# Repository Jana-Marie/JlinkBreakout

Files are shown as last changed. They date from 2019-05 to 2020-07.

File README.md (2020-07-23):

# JlinkBreakout

Segger Jlink to Tag-Connect/SWD breakout board.

## [V2](V2/)
Notes:
 - Use a right-angle 2 row, 20 position 0.1" (2.54mm) female header/socket
     + https://lcsc.com/product-detail/Pin-Header-Female-Header_Ckmtw-Shenzhen-Cankemeng-C124406_C124406.html
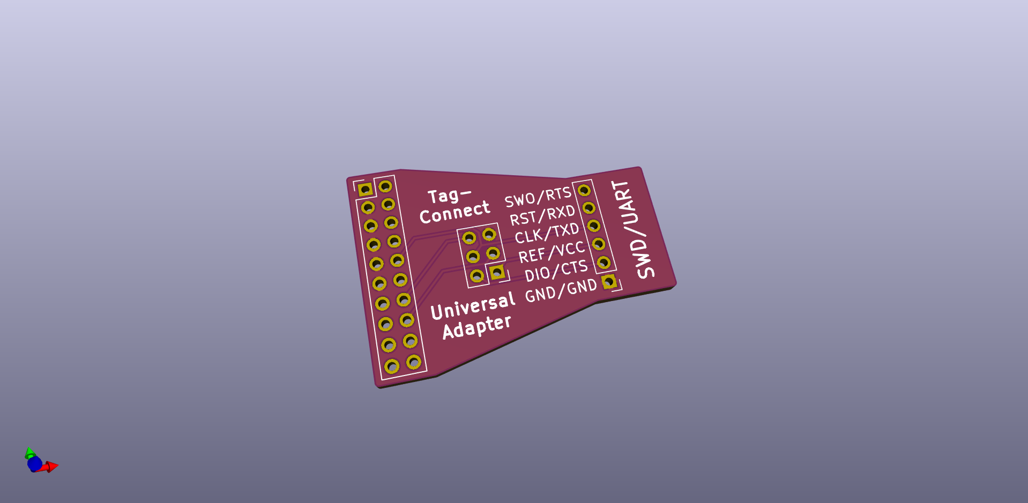
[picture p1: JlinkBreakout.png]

## [V3](V3/)
- Adds a voltage regulator with selectable output voltage (3.3V, 2.5V, 1.8V, External power)
- JST-XH connector for SWD
- 2x3 IDC Tag-connect header
- JTAG connector is standard 2 row, 20 position 0.1" (2.54mm) female header/socker, mounted on pcb edge
    + https://lcsc.com/product-detail/Pin-Header-Female-Header_BOOMELE-Boom-Precision-Elec-C30867_C30867.html
        * Pin thickness: 0.32mm to .064mm
        * Pin-pin clearance: 2.22mm to 1.9mm
    + Standard 1.6mm (0.062") PCB should be solderable, but there will be a gap, or 2mm (0.079") PCB would leave less clearance
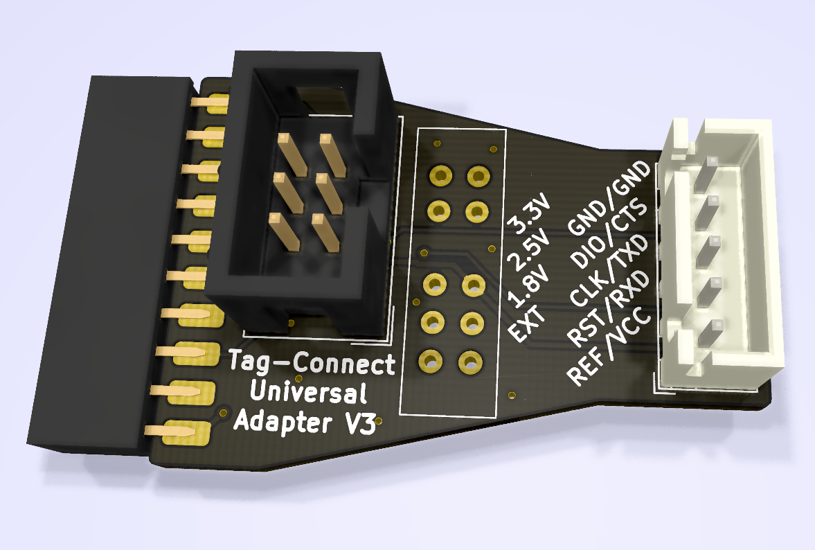
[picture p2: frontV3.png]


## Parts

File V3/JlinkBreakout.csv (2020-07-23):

Reference | Quantity | Value | Footprint | Datasheet | LCSC
C1 C2 | 2 | 2.2u | Capacitor_SMD:C_0805_2012Metric | ~ | C49217
J1 | 1 | JLINK | otter:conn_02x10_edge | ~ | C30867
J2 | 1 | TC | Connector_IDC:IDC-Header_2x03_P2.54mm_Vertical | ~ | C11214
J3 | 1 | SWD | Connector_JST:JST_XH_B5B-XH-A_1x05_P2.50mm_Vertical | ~ | C161872
R1 | 1 | 10k | Resistor_SMD:R_0603_1608Metric | ~ | C25804
R2 | 1 | 20.35k | Resistor_SMD:R_0603_1608Metric | ~ | C22910
R3 | 1 | 9.31k | Resistor_SMD:R_0603_1608Metric | ~ | C23126
R4 | 1 | 5.76k | Resistor_SMD:R_0603_1608Metric | ~ | C23070
U1 | 1 | SGM2019 | Package_TO_SOT_SMD:SOT-23-5 |  | C24330
U2 | 1 | switch_0204 | otter:SS-24E06-TG |  | C221978

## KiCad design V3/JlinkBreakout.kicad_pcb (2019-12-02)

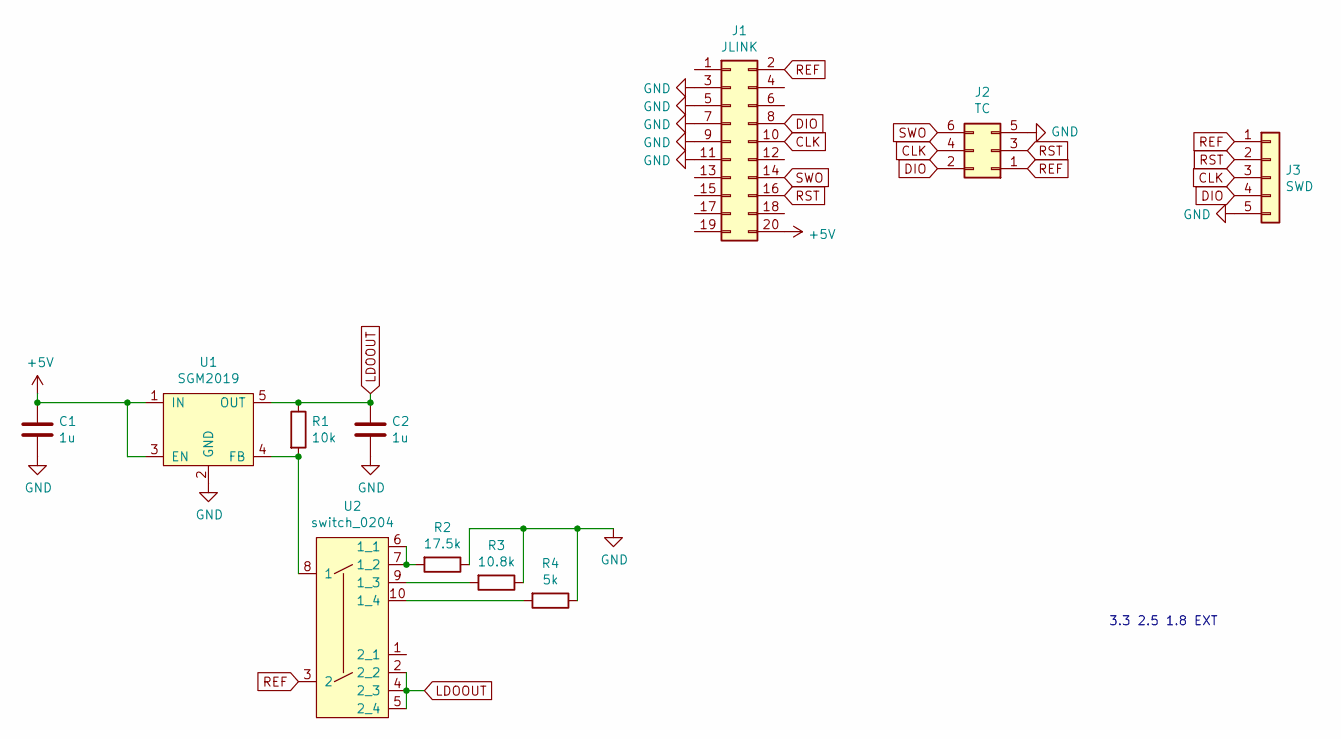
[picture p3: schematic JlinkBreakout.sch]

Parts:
C1, C2: 1u; C_0805_2012Metric
J1: JLINK; conn_02x10_edge
J2: TC; IDC-Header_2x03_P2.54mm_Vertical
J3: SWD; JST_XH_B5B-XH-A_1x05_P2.50mm_Vertical
R1: 10k; R_0603_1608Metric
R2: 17.5k; R_0603_1608Metric
R3: 10.8k; R_0603_1608Metric
R4: 5k; R_0603_1608Metric
U1: SGM2019; SOT-23-5
U2: switch_0204; SS-24E06-TG

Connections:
+5V: C1.1, J1.20, U1.1 (IN), U1.3 (EN)
CLK: J1.10, J2.4, J3.3
DIO: J1.8, J2.2, J3.4
GND: C1.2, C2.2, J1.3, J1.5, J1.7, J1.9, J1.11, J2.5, J3.5, R2.1, R3.1, R4.1, U1.2 (GND)
LDOOUT: C2.1, R1.1, U1.5 (OUT), U2.2 (2_2), U2.4 (2_3), U2.5 (2_4)
unnamed: R1.2, U1.4 (FB), U2.8 (1)
unnamed: R2.2, U2.6 (1_1), U2.7 (1_2)
unnamed: R3.2, U2.9 (1_3)
unnamed: R4.2, U2.10 (1_4)
REF: J1.2, J2.1, J3.1, U2.3 (2)
RST: J1.16, J2.3, J3.2
SWO: J1.14, J2.6

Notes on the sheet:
3.3 2.5 1.8 EXT

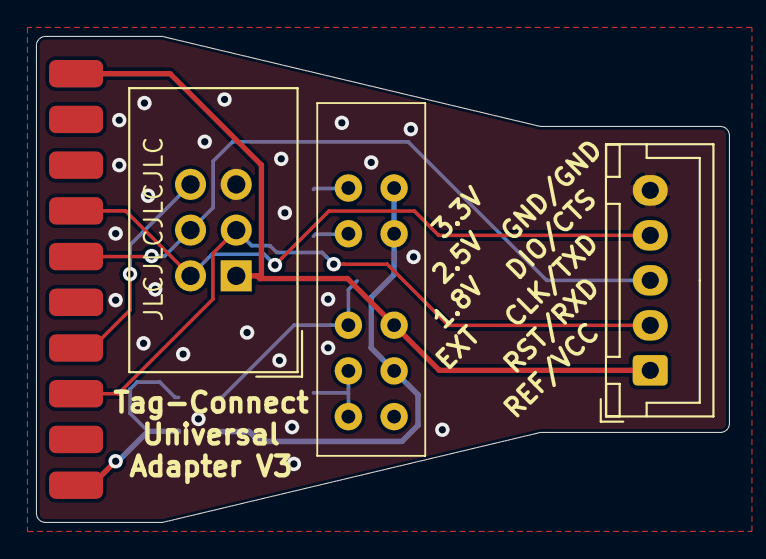
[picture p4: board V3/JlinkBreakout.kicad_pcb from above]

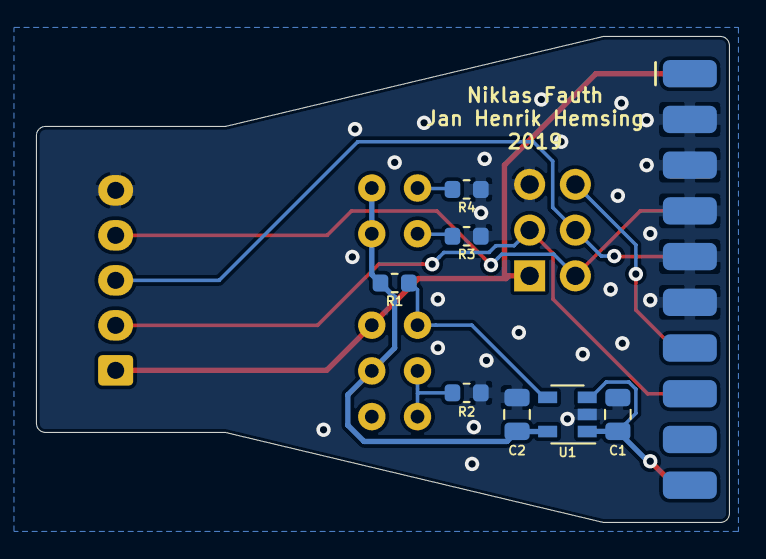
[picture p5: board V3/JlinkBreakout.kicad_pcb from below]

Board: 2 copper layers, 38.5 x 27.0 mm, 11 parts (7 on the bottom side), 12 nets.

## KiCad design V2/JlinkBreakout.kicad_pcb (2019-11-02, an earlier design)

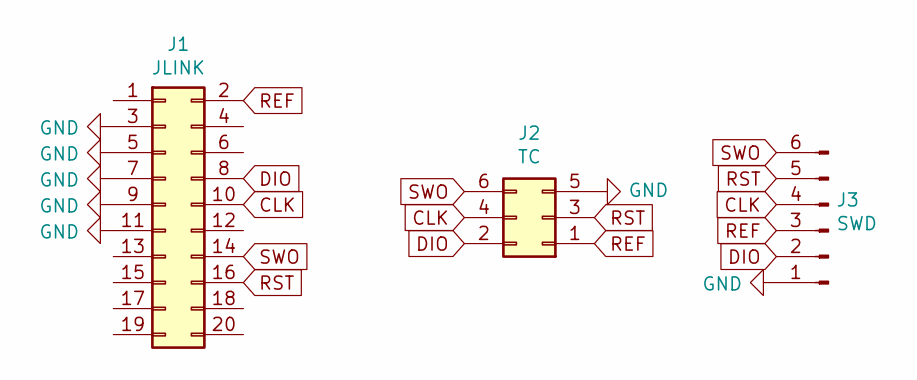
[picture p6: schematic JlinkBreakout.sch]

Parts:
J1: JLINK; PinHeader_2x10_P2.54mm_Vertical
J2: TC; PinHeader_2x03_P2.54mm_Vertical
J3: SWD; PinHeader_1x06_P2.54mm_Vertical

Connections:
CLK: J1.10, J2.4, J3.4
DIO: J1.8, J2.2, J3.2
GND: J1.3, J1.5, J1.7, J1.9, J1.11, J2.5, J3.1
REF: J1.2, J2.1, J3.3
RST: J1.16, J2.3, J3.5
SWO: J1.14, J2.6, J3.6

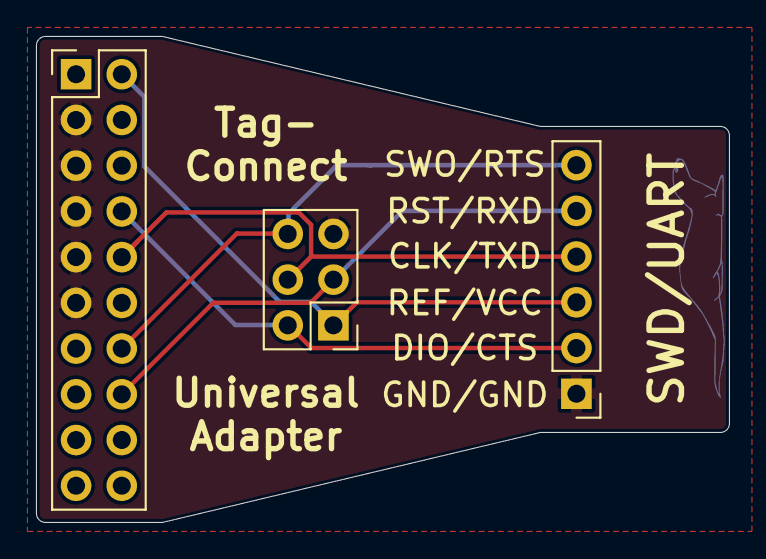
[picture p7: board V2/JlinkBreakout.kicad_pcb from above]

Board: 2 copper layers, 38.5 x 27.0 mm, 3 parts (0 on the bottom side), 6 nets.

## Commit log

2019-05-06 initital commit
    [JlinkBreakout-B_Cu.gbl, JlinkBreakout-B_Mask.gbs, JlinkBreakout-B_Paste.gbp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]
2019-05-06 added gerber
    [JlinkBreakout.kicad_pcb]
2019-11-01 created V2
    [JlinkBreakout-B_Cu.gbl, JlinkBreakout-B_Mask.gbs, JlinkBreakout-B_Paste.gbp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]
2019-11-02 finalized V2
    [JlinkBreakout-B.Cu.gbl, JlinkBreakout-B.Mask.gbs, JlinkBreakout-B.Paste.gbp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]
2019-11-02 removed old files
    [JlinkBreakout.kicad_pcb, JlinkBreakout.sch]
2019-11-02 moved V2 to V3
    [JlinkBreakout-B.Cu.gbl, JlinkBreakout-B.Mask.gbs, JlinkBreakout-B.Paste.gbp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]
2019-11-02 moved V1 to V2
    [JlinkBreakout-B.Cu.gbl, JlinkBreakout-B.Mask.gbs, JlinkBreakout-B.Paste.gbp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]
2019-11-02 added V2
    [JlinkBreakout-B_Cu.gbl, JlinkBreakout-B_Mask.gbs, JlinkBreakout-B_Paste.gbp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]
2019-11-02 removed V1
    [JlinkBreakout-B_Cu.gbl, JlinkBreakout-B_Mask.gbs, JlinkBreakout-B_Paste.gbp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]
2019-11-02 updated gerber
    [JlinkBreakout-B.Cu.gbl, JlinkBreakout-B.Mask.gbs, JlinkBreakout-B.Paste.gbp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]
2019-11-26 updated Resistor values
    [JlinkBreakout.kicad_pcb]
2019-12-02 fixed footprint
    [JlinkBreakout-B.Cu.gbl, JlinkBreakout-B.Mask.gbs, JlinkBreakout-B_Cu.gbl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]
2020-07-22 Add V3 BOM
    [JlinkBreakout.csv]
